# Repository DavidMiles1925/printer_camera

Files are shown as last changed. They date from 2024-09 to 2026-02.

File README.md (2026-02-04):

# Printer Camera

## Project Description

This project was conceived because I have a resin 3D printer that I want to run outside. Because the printer is outside, I need to leave it blocked from sunlight. Therefore, I cannot check on the print by lifting the lid (at least not during the daytime).

The project has now been through 2 interations; once with my Creality LD-002H and again with my Elegoo Mars 5 Ultra.

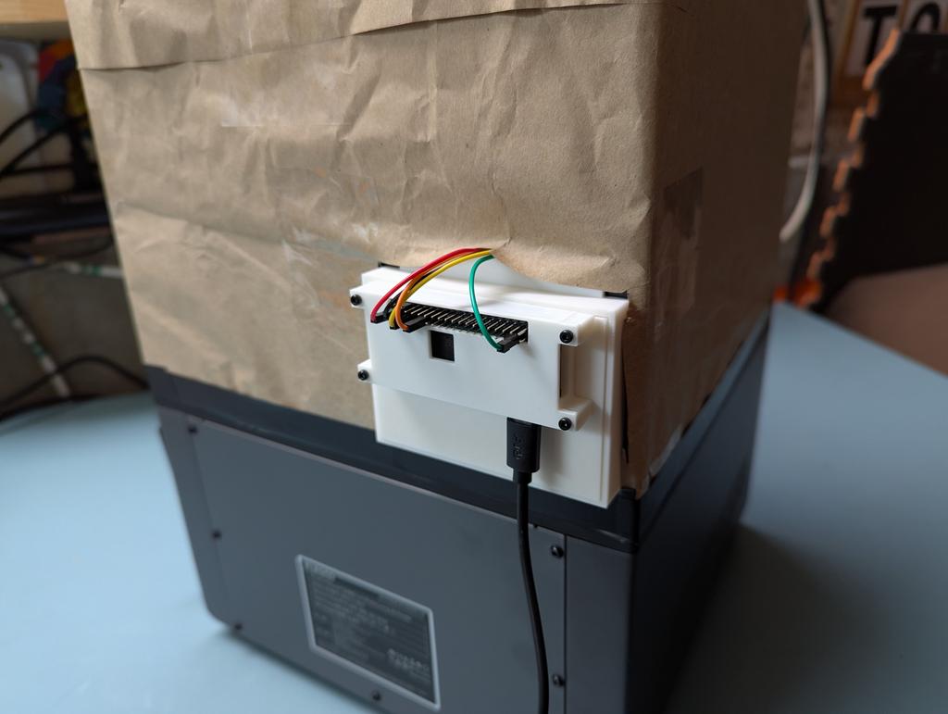
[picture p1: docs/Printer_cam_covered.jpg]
Version 2


### Features

    ✅ Turns on a camera on a set interval
    ✅ Turns on a camera with ad hoc command and/or separate program
    ✅ Turn on light(s) before recording with the camera (and off after recording)
    ✅ Turns on light with ad hoc command and/or separate program
    ✅ Store videos on SSD to be accessed via SSH
    ✅ Record temperature in a log to be accessed via SSH
    ✅ Fully 3D printed shell
    ✅ A script to run on Windows machine for downloading files from the RPi

## Using the Software

### Clone Repo:

```bash
git clone https://github.com/DavidMiles1925/printer_camera.git
```

### Dependencies:

**Note: These _MUST_ be installed prior to using this software.**

#### picamera2

> This is the library used to interact with the RPi Camera Module
>
> ```bash
> sudo apt install -y python3-picamera2
> ```

#### ffmpeg

> This library gets used to convert .h264 files to .mp4.
>
> ```bash
> sudo apt install -y ffmpeg
> ```

#### paramiko scp

> This will be installed on your **_WINDOWS MACHINE_** to bring files over from the pi.
>
> Ensure that you have set up an SSH Key. [**Documentation for SSH Key Setup Here**](https://github.com/DavidMiles1925/pi_zero_setup#set-up-ssh-key-to-eliminate-need-for-password)
>
> ```bash
> pip install paramiko scp
> ```

### Programs

All programs should be run from the command line.

Options can be configured in `config.py`.

#### `main.py`

> This runs the main app which takes a video every `{CAMERA_RECORDING_TIME}` seconds.
>
> **Before running make sure these options are configured!**
>
> `SAVE_DIRECTORY_PATH` and `LOG_DIRECTORY_PATH` have the correct Pi Name in their directory path.
>
> `FILENAME_PREFIX` has a descriptor that acurately describes the material being recorded.
>
> | Option                         | Possible Values                                 | Purpose                                                                                              |
> | :----------------------------- | :---------------------------------------------- | :--------------------------------------------------------------------------------------------------- |
> | `VIDEO_RECORDING_ON`           | True/False                                      | Turn video recording feature on or off                                                               |
> | `CAMERA_RECORDING_TIME`        | Any Number                                      | Seconds that the camera will record if activated                                                     |
> | `TIME_BETWEEN_LOOP_ITERATIONS` | Any Number                                      | Seconds between checks for feature activation (not including the length of the video recording)      |
> | `FILENAME_PREFIX`              | Any String - Do NOT include spaces in the name. | This is will be filename, followed by a number                                                       |
> | `DIRECTORY_NAME_PREFIX`        | Any String                                      | This is the directory name prefix where videos will be stored                                        |
> | `SAVE_DIRECTORY_PATH`          | "/home/[PI NAME]/printer_camera/recordings/"    | The directory where recordings will be stored                                                        |
> | `LIGHTING_ON`                  | True/False                                      | This determines whether the light will turn on WHILE THE CAMERA IS RUNNING                           |
> | `LIGHT_ALWAYS_ON`              | True/ False                                     | This will determine if the light is ALWAYS ON while the program is running EVEN IF THE CAMERA IS NOT |
> | `LOG_DIRECTORY_PATH`           | "/home/[PI NAME]/printer_camera/logs"           | This is the directory name prefix where logs will be stored                                          |

#### `temp.py`

> This program, when run by iteself, will log the current temperature and print it to the console intermitently.
>
> This module is used in main.py to log the temperature each time the camera records a video.
>
> | Option                   | Possible Values | Purpose                                                                       |
> | :----------------------- | :-------------- | :---------------------------------------------------------------------------- |
> | `TEMPERATURE_LOGGING_ON` | True/False      | This determines whether the temperature will be logged when `main.py` is run. |
> | `TEMP_LOG_TIME_`         | Any Number      | The amount of time in seconds between logging when **`temp.py`** is run       |

#### `camera_and_light.py`

> This program is a stand-alone app used for testing the camera or grabbing an ad hoc picture/video.
>
> It can also be used to toggle lights in the chamber on and off.
>
> Photos are saved in .jpg format.
>
> Videos are stored in .mp4 format (after being converted from .h264)
>
> | Option                  | Possible Values      | Purpose                                                                  |
> | :---------------------- | :------------------- | :----------------------------------------------------------------------- |
> | `SINGLE_RECORDING_TIME` | Any Number           | The length of the video to be recorded in seconds                        |
> | `LIGHT_PIN_1`           | BCM number from GPIO | This pin will be used for an LED to light the chamber                    |
> | `LIGHT_PIN_2`           | BCM number from GPIO | This pin will be used for an LED to light the chamber                    |
> | `DISABLE_CAMERA`        | True/False           | Turn to `True` to be able to disconnect RPi Camera Module without errors |

#### pull_files.py

> This program is only to be run on a windows machine.
>
> You **_MUST_** have set up an SSK Key. [**Documentation for SSH Key Setup Here**](https://github.com/DavidMiles1925/pi_zero_setup#set-up-ssh-key-to-eliminate-need-for-password)
>
> | Option              | Possible Values  | Purpose                                           |
> | :------------------ | :--------------- | :------------------------------------------------ |
> | `REMOTE_HOST`       | RPi IP Address   | The IP address of the RPi for ssh connection      |
> | `PI_USERNAME`       | RPi Username     | The username of the RPi                           |
> | `WIN_USERNAME`      | Windows Username | The username of the Windows account pulling files |
> | `REMOTE_PATH_PHOTO` | File Path        | Path to grab photo files from                     |
> | `REMOTE_PATH_VIDEO` | File Path        | Path to grab video files from                     |
> | `LOCAL_PATH`        | File path        | Path where files will be downloaded               |
>
> **Manual Copy/Paste commands to pull videos.**
>
> ```bash
> scp -r PI_NAME@192.168.1.000:/home/PI_NAME/printer_camera/recordings/ /c/users/USER_NAME/downloads
> scp -r PI_NAME@192.168.1.000:/home/PI_NAME/printer_camera/logs/ /c/users/USER_NAME/downloads
> ```

---

## Developer Notes

The majority of the original code as repurposed from the [**motion_camera**](https://github.com/DavidMiles1925/motion_camera) repo. Look there for more detailed documetnation.

### Materials

| Material | Quantity | Link |
| :--- | :---: | :--- |
| Raspberri Pi Zero 2 W (with header pins) | 1 | |
| SD Card Formatted with Raspberry Pi OS | 1 | |
| Raspberri Pi Camera Module | 1 | |
| Breadboard | 1 | |
| 3D Printed Shell | 2 | [Printed Shell](./print_files/) |
| 100Ω Resistor (for lights) | 2 | |
| 4.7KΩ Resistor (for temperature sensor)  | 1 | |
| DuPont Cables M-F (short) | 5 | |

### Wiring

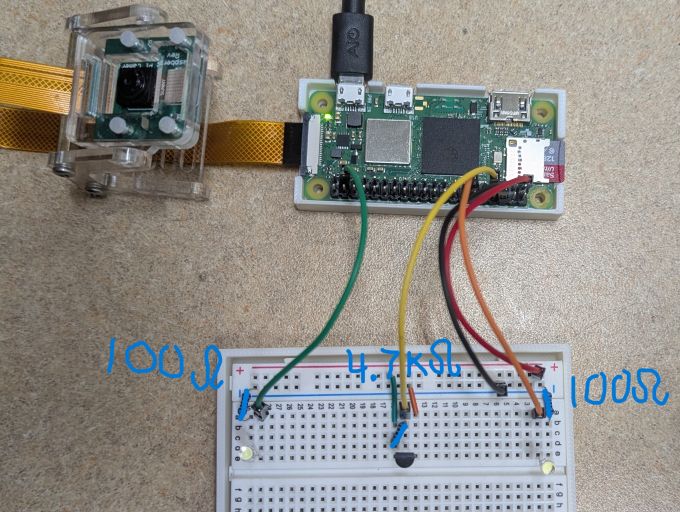
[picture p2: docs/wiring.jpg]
Wiring


### Pin assignments:

| Pin Name | Pin Number (BCM) | Purpose |
| :--- | :--- | :--- |
| LIGHT_1_PIN | 17 | Lighting: Brightening the printing chamber |
| LIGHT_2_PIN | 26 | Lighting: Brightening the printing chamber |
| N/A | GND (any) | Lighting: Ground |
| 1-Wire Connection | 4 | Temperature Sensor: THIS WILL REQUIRE ADDITIONAL STEPS |
| N/A | GND (any) | Temperature Sensor: Ground |
| N/A | 5V | Temperature Sensor: Power |

**PiCamera must be properly connected or program will not run.**

### Camera

#### Camera Installation

> You will need to ensure picamera2 is installed on your machine. (see Dependencies above)
>
> I have documented the setup of the camera extensively in the [**Motion Camera Repo**](https://github.com/DavidMiles1925/motion_camera). Refer to this documentation for more information.
>
> Ensure the camera is installed (in the RPI Zero 2 W) with the gold traces facing the board ("face-down").
>
> The side of the camera with the cable running in is the bottom of the camera.
>
> The RPi must be booted with the camera attached. If it is attached afterwards, the program will throw an error.

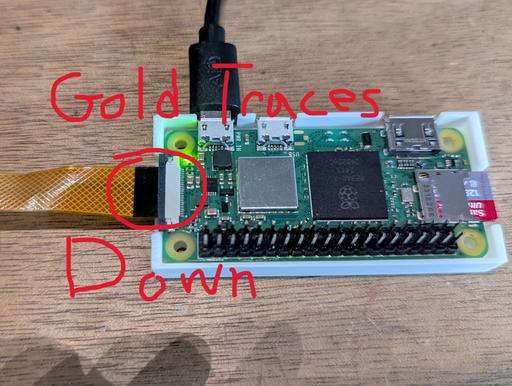
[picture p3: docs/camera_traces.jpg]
Camera Traces


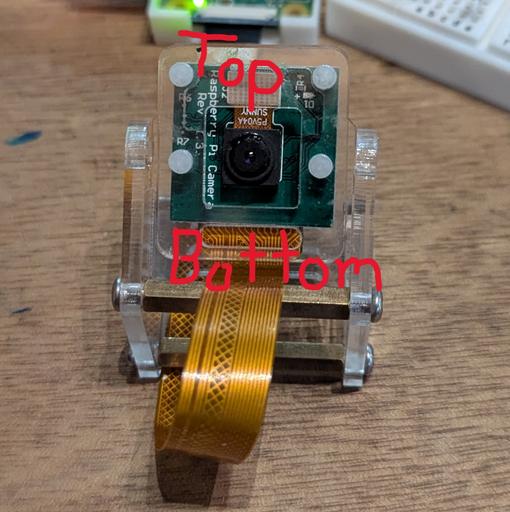
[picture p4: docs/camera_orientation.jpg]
Camera Orientation


### Temperature Sensor: DS18B20

#### One-Wire Interface

One-Wire Interface needs to be enabled to read the data pin. Do this in the RPi config.

**[Documentation](https://pinout.xyz/pinout/1_wire)** can be found here.

**[Tutorial](https://www.circuitbasics.com/raspberry-pi-ds18b20-temperature-sensor-tutorial/)** can be found here.

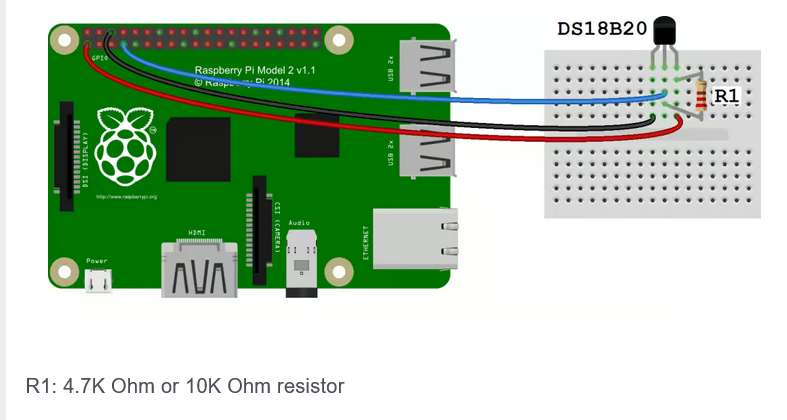
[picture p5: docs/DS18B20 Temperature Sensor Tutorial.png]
Temp Sensor


1. Add to /boot/config.txt

Run the raspberry pi config tool

```bash
sudo raspi-config
```

Select `Interface Options`

Select `1-Wire` and Select "Yes"

2. Reboot

```bash
sudo reboot
```

3. We need to add a bootable kernal to Linux:

```bash
sudo modprobe w1-gpio
sudo modprobe w1-therm
```

4. Change directories and check for attached device:

```bash
cd /sys/bus/w1/devices
ls
```

5. Enter device directory:

```bash
cd 28-XXXXXXXXXXXX
```

6. Check raw temperature readout:

```bash
cat w1_slave
```

#### Code for Temp Sensor

**About**

The library `temp.py` was created using code from the tutorial referenced above.

It was adjusted so that it can be used as a library as well as run as a main function.

The above steps will need to be completed before the code can be run.

**Integration**

I set up the log function to take `prefix=` argument in order to accomodate the temp log.

## 3D Prints

The Version 1 files have been moved to the `/Depricated` folder and will not be used anymore.

Files are located in the `print_files` folder above. The Pi piece and the breadboard piece were glued back-to-back and installed in the fan port on the cover for the Mars 5 Ultra.

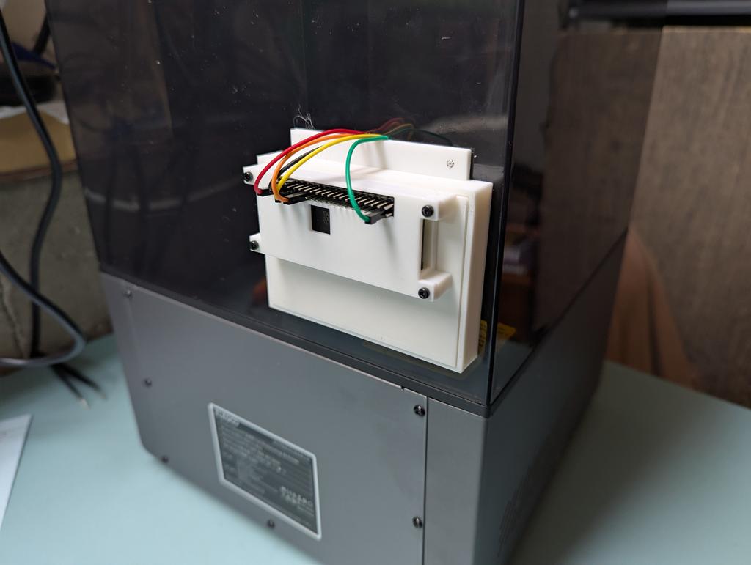
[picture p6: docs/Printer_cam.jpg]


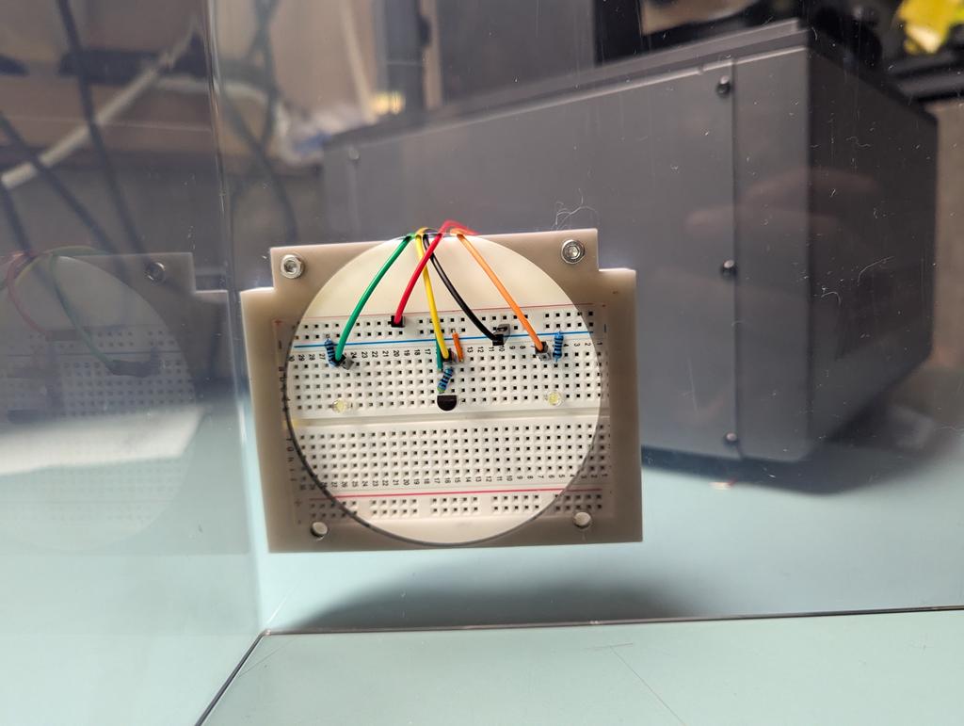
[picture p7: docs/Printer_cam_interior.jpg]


## Gallery

Version 1

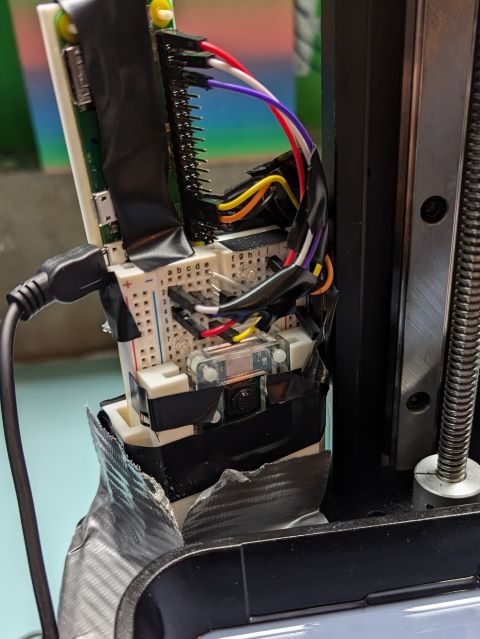
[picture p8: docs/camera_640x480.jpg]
Version 1


Version 2

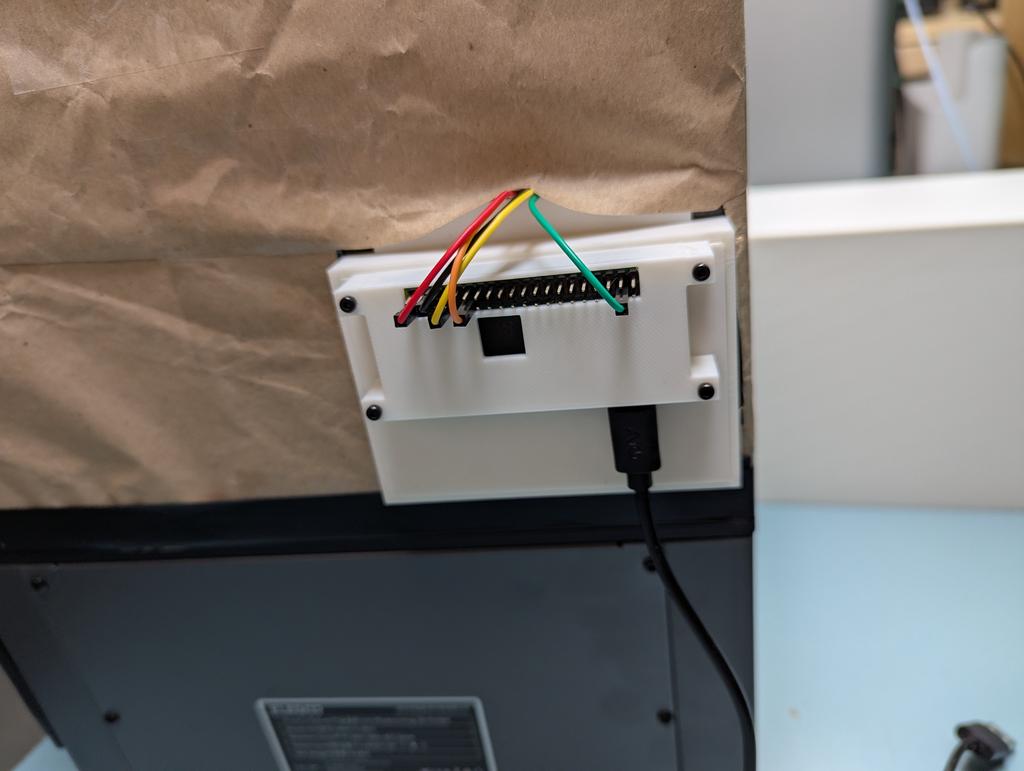
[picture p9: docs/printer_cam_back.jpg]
Version 2 Back


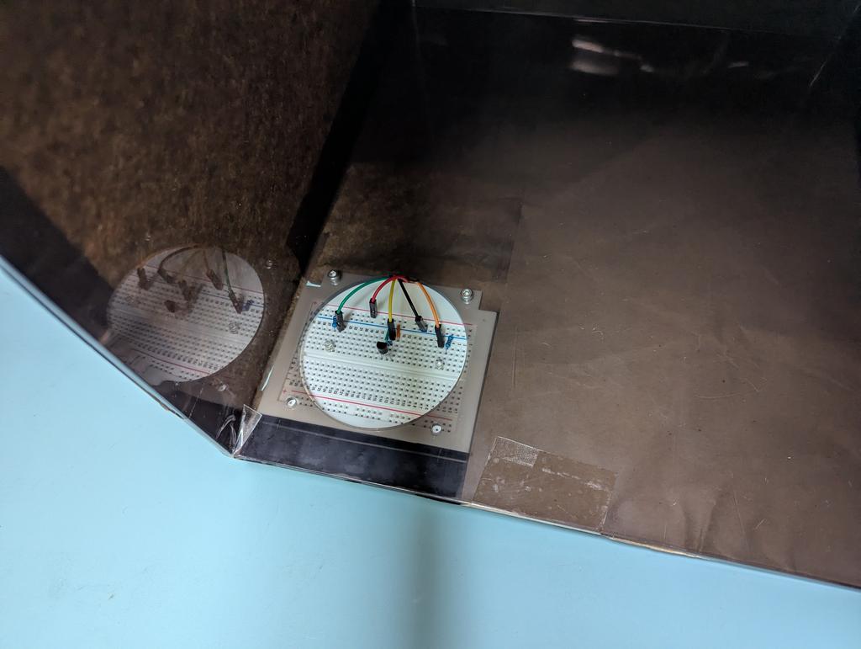
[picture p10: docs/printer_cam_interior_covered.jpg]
Version 2 Interior


#### Other Documentaion Links

**My article on printing outdoors**  
[Article - Outdoor Resin Printinig](https://www.crealitycloud.com/post-detail/66e5a9818b2f34a688458715)

**My YouTube video showing outdoor printing**  
[Video - Outdoor Resin Printing](https://youtu.be/wVPIBC5VqVw)

**Resin Settings from Maker Trainer (for LD-002H)**  
[LD-002H Resin Settings Spreadsheet](https://makertrainer.com/wiki/Creality_LD-002H_resin_settings)

**Resin Settings from Elegoo (for Mars 5 Ultra)**  
Elegoo Resin Settings

**Calibration Model and Tutorial from Ameralabs**  
[Calibration Tutorial](https://ameralabs.com/blog/town-calibration-part/)

## Troubleshooting

### Camera

#### IndexError: list index out of range

means that picamera2 checked for attached cameras but found an empty list.

1. Check physical connection

- Is the camera ribbon cable firmly seated in the CSI port?

- Make sure it's facing the correct direction (metal pins face the camera connector contacts).

- Try reseating the cable on both ends (Pi and camera).

2. Make sure the camera is enabled

Even if you already ran this, double-check:

```bash
sudo raspi-config
```

- Go to: Interface Options → Camera → Enable

#### TypeError: Picamera2.start_recording() missing 1 required positional argument: 'output'

The start_recording() method in picamera2 requires two arguments:

`picam2.start_recording(output, encoder)`

You're currently just passing the filename (filename), but it's expecting a file encoder and a file-like output.

#### 🧪 Test It

After reboot:

libcamera-hello

If it still fails:

    Double-check that your cable is for the Pi Zero (not the wide one for full-size Pis).

    Make sure the camera module itself is firmly connected and supported by the OS.

    Run:

libcamera-still --list-cameras

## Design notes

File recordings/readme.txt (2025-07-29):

This file needs to be here so that this directory is here when the repo is cloned.
Yay stupid solutions!

Update: See camera.py for how to update so I don't need this file!

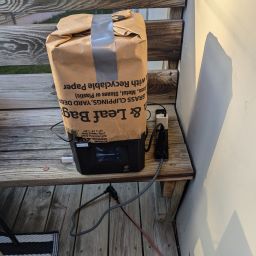
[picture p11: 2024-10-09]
docs/outside.jpg

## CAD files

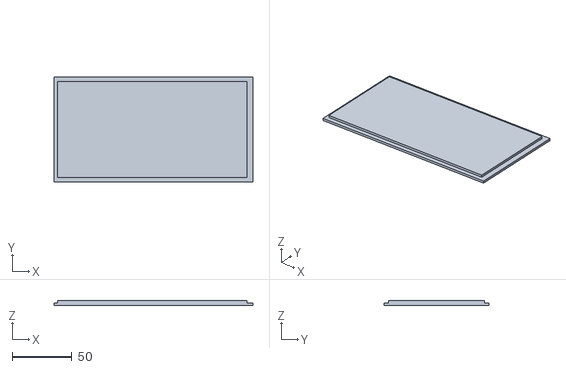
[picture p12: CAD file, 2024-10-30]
print_files/Depricated/Wash_Bin_LD-002H_Build_Volume_Lid.stl
166.0 x 88.0 x 4.00

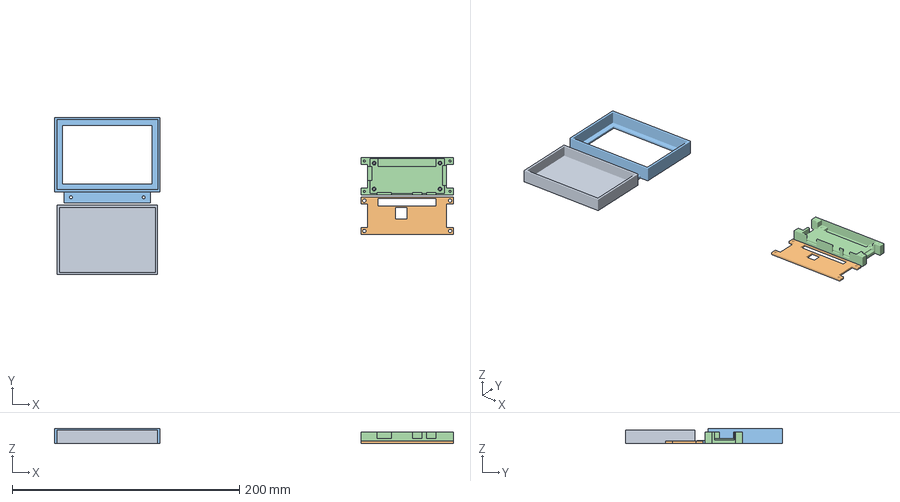
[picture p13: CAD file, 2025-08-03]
print_files/Printer Camera 3D Printed Shell.3mf
351.3 x 138.2 x 13.2 mm
Breadboard Base.stl
Pi Cover.stl
Breadboard Cover.stl
Pi Base.stl

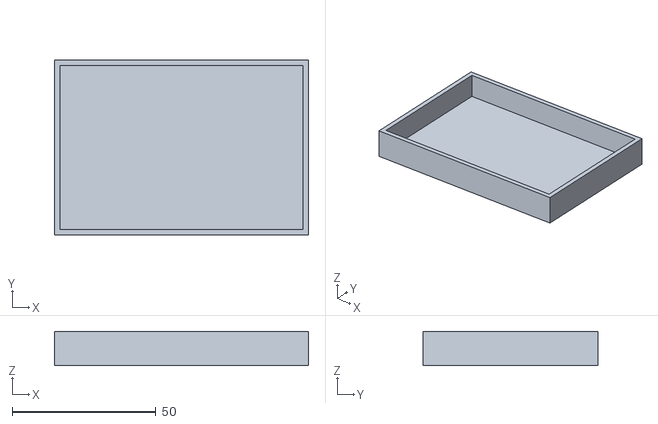
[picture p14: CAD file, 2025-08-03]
print_files/Breadboard Base.stl
88.5 x 61.0 x 12.0

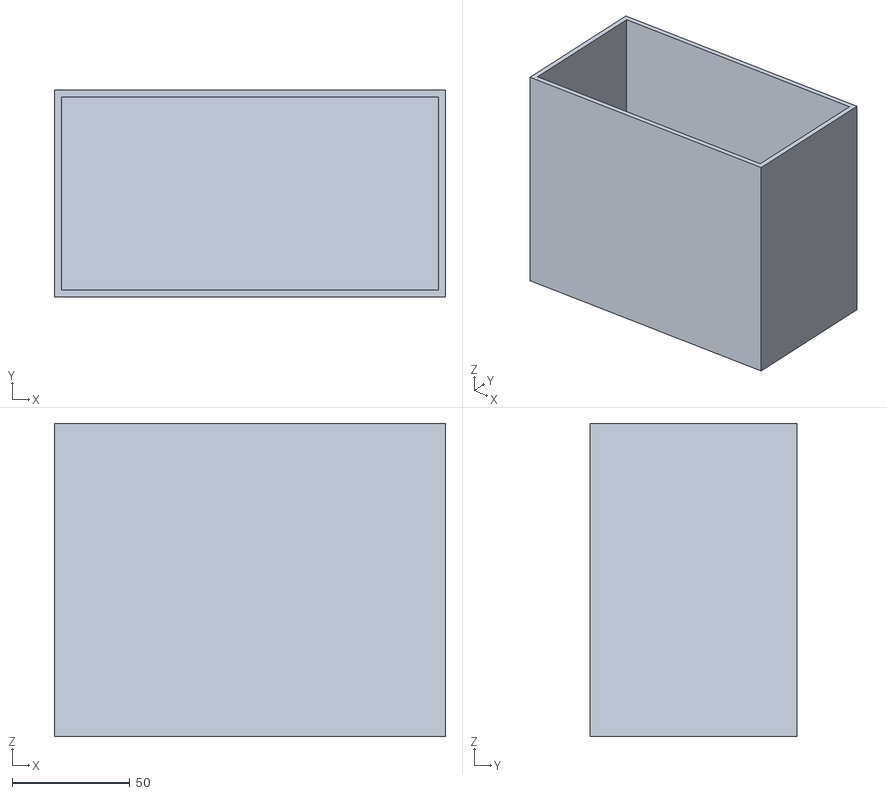
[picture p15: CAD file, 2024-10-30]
print_files/Depricated/Wash_Bin_LD-002H_Build_Volume.stl
166.0 x 88.0 x 133.0

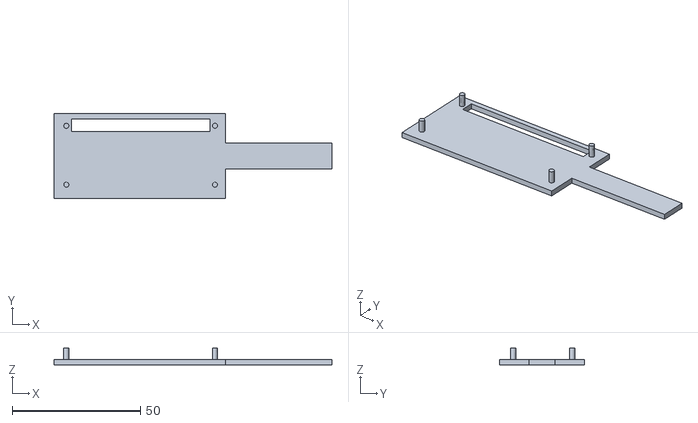
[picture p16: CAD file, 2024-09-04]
print_files/Depricated/Printer_Camera_Holder_Pi_Extension.stl
108.5 x 33.0 x 6.50

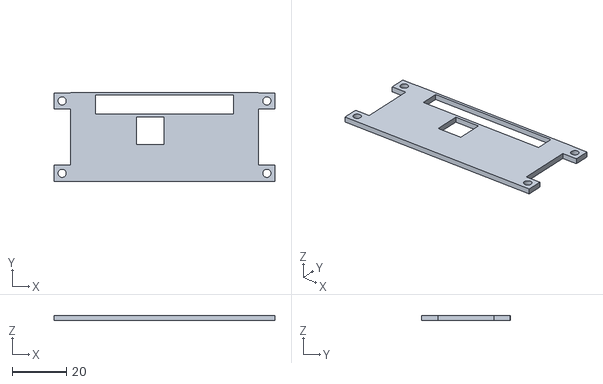
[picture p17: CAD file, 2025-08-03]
print_files/Pi Cover.stl
81.5 x 32.8 x 2.00

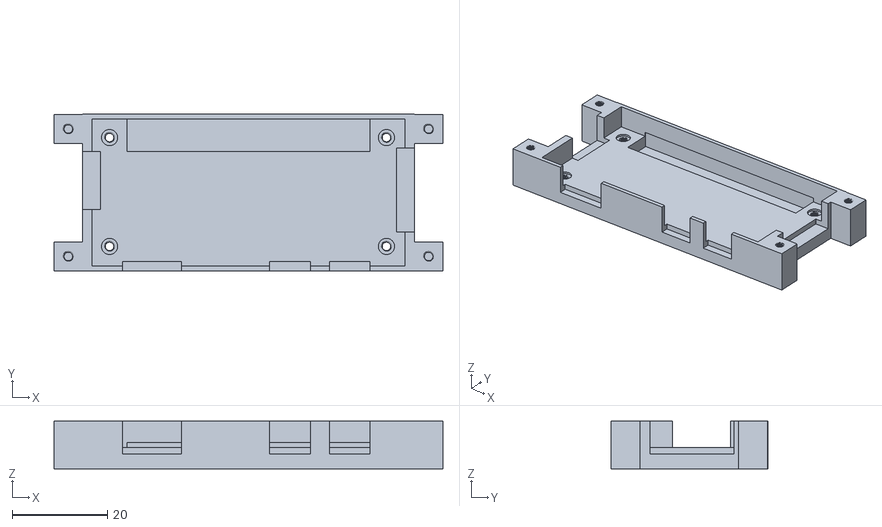
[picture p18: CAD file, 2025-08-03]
print_files/Pi Base.stl
81.5 x 32.8 x 10.0

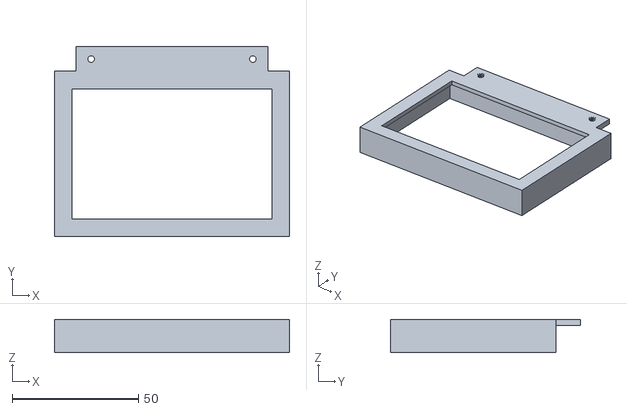
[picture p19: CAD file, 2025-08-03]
print_files/Breadboard Cover.stl
93.0 x 75.2 x 13.2

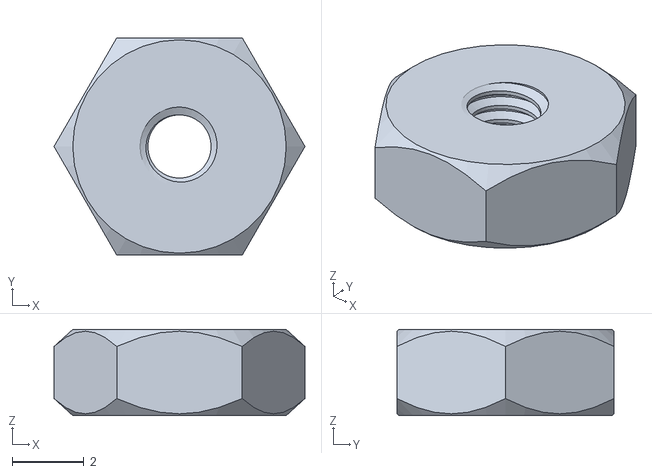
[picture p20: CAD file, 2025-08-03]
print_files/NUT_TEST.stl
6.99 x 6.05 x 2.40

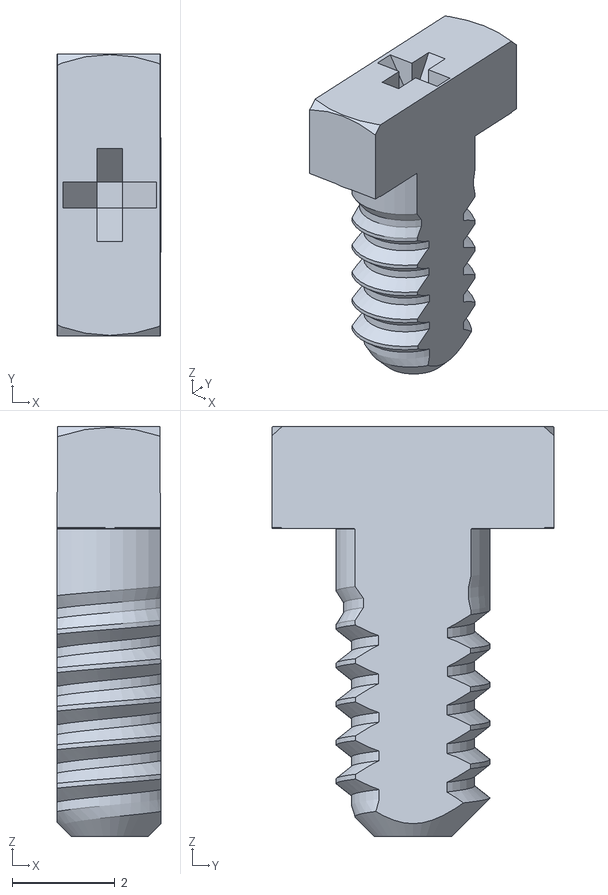
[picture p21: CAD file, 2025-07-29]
print_files/Pi Bolt.stl
2.03 x 5.50 x 7.98

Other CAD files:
print_files/Printer Camera Models.blend

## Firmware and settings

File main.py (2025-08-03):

from datetime import datetime
import RPi.GPIO as GPIO
import os
from picamera2.encoders import H264Encoder
from picamera2 import Picamera2
from time import sleep
from logger import write_to_log

from config import TIME_BETWEEN_LOOP_ITERATIONS, FILENAME_PREFIX, DIRECTORY_NAME_PREFIX, SAVE_DIRECTORY_PATH, CAMERA_RECORDING_TIME, LIGHTING_ON, VIDEO_RECORDING_ON, TEMPERATURE_LOGGING_ON, LIGHT_ALWAYS_ON
from temp import read_temp, construct_temp_string

LIGHT_1_PIN = 17
LIGHT_2_PIN = 26

video_counter = 0
recordings_path_str = "none"

picam2 = Picamera2()
video_config = picam2.create_video_configuration()
picam2.configure(video_config)
encoder = H264Encoder(bitrate=1000000)

# Adds zeros to the video number in the filename.
#   - This was done to ensure videos stayed in chronological
#     order, even when displayed alphabetically.
def add_zeros_to_number(num, amt):
    num_str = str(num)

    num_zeros = amt - len(num_str)

    if num_zeros > 0:
        return '0' * num_zeros + num_str
    else:
        return num_str
    
def setup_pins():
    GPIO.setmode(GPIO.BCM)

    GPIO.setwarnings(False)

    GPIO.setup(LIGHT_1_PIN, GPIO.OUT)
    GPIO.output(LIGHT_1_PIN, GPIO.LOW)

    GPIO.setup(LIGHT_2_PIN, GPIO.OUT)
    GPIO.output(LIGHT_2_PIN, GPIO.LOW)

def set_up_folder():
    global recordings_path_str
    folder_time = datetime.now().strftime("%m.%d.%Y")

    recordings_path_str = f"{SAVE_DIRECTORY_PATH}{DIRECTORY_NAME_PREFIX}{folder_time}"
    
    if os.path.isdir(recordings_path_str) ==  False:
        os.mkdir(recordings_path_str)

    os.chdir(recordings_path_str)

def run_camera():
    global video_counter

    if LIGHT_ALWAYS_ON == False:
        switch_lights(True)

    timestamp = datetime.now().strftime("%H.%M.%S")

    video_counter_str = add_zeros_to_number(video_counter, 3)

    output = FILENAME_PREFIX + "_" + timestamp + ".h264"
    mp4_output = f"{video_counter_str}-{FILENAME_PREFIX}-[{timestamp}].mp4"

    print("Camera Running")

    picam2.start_recording(encoder, output)

    sleep(CAMERA_RECORDING_TIME)
    
    picam2.stop_recording()

    if LIGHT_ALWAYS_ON == False:
        switch_lights(False)

    print(f"Recorded {output}\nConverting to MP4...")

    # Convert H264 to MP4
    conversion_command = f"ffmpeg -i {output} -c copy {mp4_output}"
    os.system(conversion_command)

    # Delete the original H264 file after conversion
    os.remove(output)

    video_counter = video_counter + 1

    print(f"Recorded {mp4_output}")
    write_to_log(f"Camera Off: Recorded {mp4_output}")

    

def switch_lights(light):
    if LIGHTING_ON == True:
        if light == True:
            GPIO.output(LIGHT_1_PIN, GPIO.HIGH)
            GPIO.output(LIGHT_2_PIN, GPIO.HIGH)

        if light == False:
            GPIO.output(LIGHT_1_PIN, GPIO.LOW)
            GPIO.output(LIGHT_2_PIN, GPIO.LOW)

if __name__ == "__main__":
    try:
        print("Program Started")
        write_to_log("Program Started")
        setup_pins()

        if LIGHT_ALWAYS_ON == True:
            switch_lights(True)
        
        while True:
            if VIDEO_RECORDING_ON == True:
                write_to_log("Running Camera")
                set_up_folder()
                run_camera()
            if TEMPERATURE_LOGGING_ON == True:
                write_to_log(construct_temp_string(), "temp_")
            sleep(TIME_BETWEEN_LOOP_ITERATIONS)

    except KeyboardInterrupt:
        print("Program terminated with ctrl+c")
        write_to_log("Program terminated with ctrl+c")
        GPIO.cleanup()

    except Exception as e:
        write_to_log(f"Error: {e}")
        print(f"Error: {e}")

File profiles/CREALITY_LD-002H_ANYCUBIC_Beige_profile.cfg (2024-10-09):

__resin:AnyCubic Beige
actualPrintingTimeHour:
actualPrintingTimeMinute:
actualPrintingTimeSecond:
antiAliasLevel:8
bAntiAliasLevelEditable:0
bAntiAliasing:1
bBottomInnerOutterCircleOffsetEnable:0
bBuildAreaOffsetEnable:0
bDisplayCorrectEnable:0
bImageBlur:0
bImageBlurPixelEditable:1
bImageMask:0
bInnerOutterCircleOffsetEnable:0
bLockXYSizeRatio:1
bPrintTimeCompensationEnable:
bShrinkageXYRatio:0
bSurfaceRoughEditable:0
bVisibleShrinkageXYRatio:1
bottomEdgeExposureMM:0
bottomEdgeExposureTimeS:4
bottomExposureTimeStrategy:0
bottomInnerCircleOffset:0
bottomLayerCount:8
bottomLayerDropHeight2:
bottomLayerDropSpeed:150
bottomLayerDropSpeed2:
bottomLayerExposureTime:12
bottomLayerLiftHeight:5
bottomLayerLiftHeight2:0
bottomLayerLiftSpeed:50
bottomLayerLiftSpeed2:0
bottomLightIntensityPWM:255
bottomLightOffTime:0
bottomLightOffTimeVisible:1
bottomOutterCircleOffset:0
bottomRestTimeAfterLift:0
bottomRestTimeAfterRetract:0
bottomRestTimeBeforeLift:0
buildAreaOffsetBottom:0
buildAreaOffsetLeft:0
buildAreaOffsetRight:0
buildAreaOffsetTop:0
circleParityDifference:0
currProfile:ANYCUBIC Beige
displayCorrectLeftBottomX:0
displayCorrectLeftBottomY:0
displayCorrectLeftTopX:0
displayCorrectLeftTopY:0
displayCorrectRightBottomX:0
displayCorrectRightBottomY:0
displayCorrectRightTopX:0
displayCorrectRightTopY:0
edgeExposureMM:0
edgeExposureTimeS:4
endGcode:"M106 S0;\nG1 Z{machine_height} F25;\nM18;\n"
fillDensity:10
fillPattern:None
imageBlurPixel:2
imageMaskFile:
innerCircleOffset:0
isHALOT:0
isSupportTSMC:0
layerGcode:"M6054 {image};show Image\nG0 Z{rise_pos} F{rise_speed};\nG0 Z{fall_pos} F{fall_speed};\nG4 P{light_delay};\nM106 S{light_pwm};light on\nG4 P{exposure_time};\nM106 S0; light off\n"
layerHeight:0.05
layerPrintTime:
lightOffTime:2
machineDepth:130.56
machineHeight:160
machineType:CREALITY LD-002H
machineWidth:82.62
maskGrayScaleUnit:4
maxGreyLevel:255
minGreyLevel:0
normalExposureTime:1.7
normalLayerDropHeight2:0
normalLayerDropSpeed:150
normalLayerDropSpeed2:0
normalLayerLiftHeight:5
normalLayerLiftHeight2:0
normalLayerLiftSpeed:50
normalLayerLiftSpeed2:0
normalLightIntensityPWM:255
normalRestTimeAfterLift:0
normalRestTimeAfterRetract:0
normalRestTimeBeforeLift:0
outterCircleOffset:0
printWaitMode:0
printingLayer:1
projectType:LCD_mirror
resinDensity:1.1399
resinPrice:25.29
resinUnit:$/L
resolutionX:1620
resolutionY:2560
shellThickness:1.2
sliceExportPart:0
softwareForecastTimeHour:
softwareForecastTimeMinute:
softwareForecastTimeSecond:
startGcode:"G21;\nG90;\nM106 S0;\nG28 Z0;\n"
surfaceRoughLevel:1
transitionLayerCount:0
transitionLayerType:0
waitModeChangedVisible:1
xShrinkageCompensation:100
yShrinkageCompensation:100
zShrinkageCompensation:100
zSlowUpDistance:0
@@ANYCUBIC Beige@@__resin:AnyCubic Beige
@@ANYCUBIC Beige@@actualPrintingTimeHour:
@@ANYCUBIC Beige@@actualPrintingTimeMinute:
@@ANYCUBIC Beige@@actualPrintingTimeSecond:
@@ANYCUBIC Beige@@antiAliasLevel:8
@@ANYCUBIC Beige@@bAntiAliasLevelEditable:0
@@ANYCUBIC Beige@@bAntiAliasing:1
@@ANYCUBIC Beige@@bBottomInnerOutterCircleOffsetEnable:0
@@ANYCUBIC Beige@@bBuildAreaOffsetEnable:0
@@ANYCUBIC Beige@@bDisplayCorrectEnable:0
@@ANYCUBIC Beige@@bImageBlur:0
@@ANYCUBIC Beige@@bImageBlurPixelEditable:1
@@ANYCUBIC Beige@@bImageMask:0
@@ANYCUBIC Beige@@bInnerOutterCircleOffsetEnable:0
@@ANYCUBIC Beige@@bLockXYSizeRatio:1
@@ANYCUBIC Beige@@bPrintTimeCompensationEnable:
@@ANYCUBIC Beige@@bShrinkageXYRatio:0
@@ANYCUBIC Beige@@bSurfaceRoughEditable:0
@@ANYCUBIC Beige@@bVisibleShrinkageXYRatio:1
@@ANYCUBIC Beige@@bottomEdgeExposureMM:0
@@ANYCUBIC Beige@@bottomEdgeExposureTimeS:4
@@ANYCUBIC Beige@@bottomExposureTimeStrategy:0
@@ANYCUBIC Beige@@bottomInnerCircleOffset:0
@@ANYCUBIC Beige@@bottomLayerCount:8
@@ANYCUBIC Beige@@bottomLayerDropHeight2:
@@ANYCUBIC Beige@@bottomLayerDropSpeed:150
@@ANYCUBIC Beige@@bottomLayerDropSpeed2:
@@ANYCUBIC Beige@@bottomLayerExposureTime:12
@@ANYCUBIC Beige@@bottomLayerLiftHeight:5
@@ANYCUBIC Beige@@bottomLayerLiftHeight2:0
@@ANYCUBIC Beige@@bottomLayerLiftSpeed:50
@@ANYCUBIC Beige@@bottomLayerLiftSpeed2:0
@@ANYCUBIC Beige@@bottomLightIntensityPWM:255
@@ANYCUBIC Beige@@bottomLightOffTime:0
@@ANYCUBIC Beige@@bottomLightOffTimeVisible:1
@@ANYCUBIC Beige@@bottomOutterCircleOffset:0
@@ANYCUBIC Beige@@bottomRestTimeAfterLift:0
@@ANYCUBIC Beige@@bottomRestTimeAfterRetract:0
@@ANYCUBIC Beige@@bottomRestTimeBeforeLift:0
@@ANYCUBIC Beige@@buildAreaOffsetBottom:0
@@ANYCUBIC Beige@@buildAreaOffsetLeft:0
@@ANYCUBIC Beige@@buildAreaOffsetRight:0
@@ANYCUBIC Beige@@buildAreaOffsetTop:0
@@ANYCUBIC Beige@@circleParityDifference:0
@@ANYCUBIC Beige@@currProfile:ANYCUBIC Gray
@@ANYCUBIC Beige@@currProfileName:ANYCUBIC Beige
@@ANYCUBIC Beige@@displayCorrectLeftBottomX:0
@@ANYCUBIC Beige@@displayCorrectLeftBottomY:0
@@ANYCUBIC Beige@@displayCorrectLeftTopX:0
@@ANYCUBIC Beige@@displayCorrectLeftTopY:0
@@ANYCUBIC Beige@@displayCorrectRightBottomX:0
@@ANYCUBIC Beige@@displayCorrectRightBottomY:0
@@ANYCUBIC Beige@@displayCorrectRightTopX:0
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

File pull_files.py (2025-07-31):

# This file is only to be used from a windows machine that has been paired with a Pi via SSH Key

from scp import SCPClient
from scp import SCPException
from time import sleep

try:
    from paramiko import SSHClient, AutoAddPolicy
    from paramiko.ssh_exception import AuthenticationException
except:
    print("\nparmiko not installed\n")
    pass

from config import REMOTE_HOST, REMOTE_PATH_PHOTO, REMOTE_PATH_VIDEO, LOCAL_PATH, PI_USERNAME

def progress(filename, size, sent):
    percent = (sent / size) * 100 if size != 0 else 100
    print(f"\rTransferring {filename}: {percent:.1f}% ({sent}/{size} bytes)", end="")

def fetch_files():
    
        print(f"Connecting to {REMOTE_HOST}...")

        ssh = SSHClient()
        ssh.set_missing_host_key_policy(AutoAddPolicy())
        ssh.connect(REMOTE_HOST, username=PI_USERNAME)  # No password needed with SSH key

        with SCPClient(ssh.get_transport(), progress=progress) as scp:
            print(f"Fetching files...")
            if REMOTE_PATH_PHOTO:
                scp.get(REMOTE_PATH_PHOTO, LOCAL_PATH, recursive=True)
            if REMOTE_PATH_VIDEO:
                scp.get(REMOTE_PATH_VIDEO, LOCAL_PATH, recursive=True)

        ssh.close()
        print(f"\n\nDone! Files copied to {LOCAL_PATH}")
        sleep(2)


if __name__ == "__main__":
    print("program started")
    sleep(1)

    try:
        fetch_files()

    except NameError as e:
        print(e.__class__)
        print(e)
        print("\n\n")
        print("HOW TO SOLVE:")
        print("If 'paramiko not installed' is displayed above, run this command:\n")
        print("pip install paramiko\n")
        print("Press any key...")
        input()


    except FileNotFoundError as e:
        print(e.__class__)
        print(e)
        print("\n\n")
        print("HOW TO SOLVE:")
        print("Configure WIN_USERNAME in the config.py file.\n")
        print("Press any key...")
        input()

    except TimeoutError as e:
        print(e.__class__)
        print(e)
        print("\n\n")
        print("HOW TO SOLVE:")
        print("Please check that the device is turned on.")
        print("Check REMOTE_HOST in the config.py file.\n")
        print("Press any key...")
        input()

    except SCPException as e:
        print(e.__class__)
        print(e)
        print("\n\n")
        print("HOW TO SOLVE:")
        print("If 'No such file or directory' is displayed above...")
        print("    Check that the file paths in config.py are correct.")
        print("    Check the file path exists.\n")
        print("Otherwise, retry running program. This error can be caused by a dropped connection.\n")
        print("Press any key...")
        input()

    except AuthenticationException as e:
        print(e.__class__)
        print(e)
        print("\n\n")
        print("HOW TO SOLVE:")
        print("Please configure PI_USERNAME in the config.py file.\n")
        print("Press any key...")
        input()

    except Exception as e:
        print(e.__class__)
        print(e)
        print("\n\n")
        print("Press any key...")
        input()

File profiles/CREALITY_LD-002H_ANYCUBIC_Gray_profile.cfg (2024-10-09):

__resin:AnyCubic Gray
actualPrintingTimeHour:
actualPrintingTimeMinute:
actualPrintingTimeSecond:
antiAliasLevel:8
bAntiAliasLevelEditable:0
bAntiAliasing:1
bBottomInnerOutterCircleOffsetEnable:0
bBuildAreaOffsetEnable:0
bDisplayCorrectEnable:0
bImageBlur:0
bImageBlurPixelEditable:1
bImageMask:0
bInnerOutterCircleOffsetEnable:0
bLockXYSizeRatio:1
bPrintTimeCompensationEnable:
bShrinkageXYRatio:0
bSurfaceRoughEditable:0
bVisibleShrinkageXYRatio:1
bottomEdgeExposureMM:0
bottomEdgeExposureTimeS:4
bottomExposureTimeStrategy:0
bottomInnerCircleOffset:0
bottomLayerCount:8
bottomLayerDropHeight2:
bottomLayerDropSpeed:150
bottomLayerDropSpeed2:
bottomLayerExposureTime:12
bottomLayerLiftHeight:5
bottomLayerLiftHeight2:0
bottomLayerLiftSpeed:50
bottomLayerLiftSpeed2:0
bottomLightIntensityPWM:255
bottomLightOffTime:0
bottomLightOffTimeVisible:1
bottomOutterCircleOffset:0
bottomRestTimeAfterLift:0
bottomRestTimeAfterRetract:0
bottomRestTimeBeforeLift:0
buildAreaOffsetBottom:0
buildAreaOffsetLeft:0
buildAreaOffsetRight:0
buildAreaOffsetTop:0
circleParityDifference:0
currProfile:ANYCUBIC Gray
displayCorrectLeftBottomX:0
displayCorrectLeftBottomY:0
displayCorrectLeftTopX:0
displayCorrectLeftTopY:0
displayCorrectRightBottomX:0
displayCorrectRightBottomY:0
displayCorrectRightTopX:0
displayCorrectRightTopY:0
edgeExposureMM:0
edgeExposureTimeS:4
endGcode:"M106 S0;\nG1 Z{machine_height} F25;\nM18;\n"
fillDensity:10
fillPattern:None
imageBlurPixel:2
imageMaskFile:
innerCircleOffset:0
isHALOT:0
isSupportTSMC:0
layerGcode:"M6054 {image};show Image\nG0 Z{rise_pos} F{rise_speed};\nG0 Z{fall_pos} F{fall_speed};\nG4 P{light_delay};\nM106 S{light_pwm};light on\nG4 P{exposure_time};\nM106 S0; light off\n"
layerHeight:0.05
layerPrintTime:
lightOffTime:2
machineDepth:130.56
machineHeight:160
machineType:CREALITY LD-002H
machineWidth:82.62
maskGrayScaleUnit:4
maxGreyLevel:255
minGreyLevel:0
normalExposureTime:1.9
normalLayerDropHeight2:0
normalLayerDropSpeed:150
normalLayerDropSpeed2:0
normalLayerLiftHeight:5
normalLayerLiftHeight2:0
normalLayerLiftSpeed:50
normalLayerLiftSpeed2:0
normalLightIntensityPWM:255
normalRestTimeAfterLift:0
normalRestTimeAfterRetract:0
normalRestTimeBeforeLift:0
outterCircleOffset:0
printWaitMode:0
printingLayer:1
projectType:LCD_mirror
resinDensity:1.1399
resinPrice:19.84
resinUnit:$/L
resolutionX:1620
resolutionY:2560
shellThickness:1.2
sliceExportPart:0
softwareForecastTimeHour:
softwareForecastTimeMinute:
softwareForecastTimeSecond:
startGcode:"G21;\nG90;\nM106 S0;\nG28 Z0;\n"
surfaceRoughLevel:1
transitionLayerCount:0
transitionLayerType:0
waitModeChangedVisible:1
xShrinkageCompensation:100
yShrinkageCompensation:100
zShrinkageCompensation:100
zSlowUpDistance:0
@@ANYCUBIC Gray@@__resin:AnyCubic Gray
@@ANYCUBIC Gray@@actualPrintingTimeHour:
@@ANYCUBIC Gray@@actualPrintingTimeMinute:
@@ANYCUBIC Gray@@actualPrintingTimeSecond:
@@ANYCUBIC Gray@@antiAliasLevel:8
@@ANYCUBIC Gray@@bAntiAliasLevelEditable:0
@@ANYCUBIC Gray@@bAntiAliasing:1
@@ANYCUBIC Gray@@bBottomInnerOutterCircleOffsetEnable:0
@@ANYCUBIC Gray@@bBuildAreaOffsetEnable:0
@@ANYCUBIC Gray@@bDisplayCorrectEnable:0
@@ANYCUBIC Gray@@bImageBlur:0
@@ANYCUBIC Gray@@bImageBlurPixelEditable:1
@@ANYCUBIC Gray@@bImageMask:0
@@ANYCUBIC Gray@@bInnerOutterCircleOffsetEnable:0
@@ANYCUBIC Gray@@bLockXYSizeRatio:1
@@ANYCUBIC Gray@@bPrintTimeCompensationEnable:
@@ANYCUBIC Gray@@bShrinkageXYRatio:0
@@ANYCUBIC Gray@@bSurfaceRoughEditable:0
@@ANYCUBIC Gray@@bVisibleShrinkageXYRatio:1
@@ANYCUBIC Gray@@bottomEdgeExposureMM:0
@@ANYCUBIC Gray@@bottomEdgeExposureTimeS:4
@@ANYCUBIC Gray@@bottomExposureTimeStrategy:0
@@ANYCUBIC Gray@@bottomInnerCircleOffset:0
@@ANYCUBIC Gray@@bottomLayerCount:8
@@ANYCUBIC Gray@@bottomLayerDropHeight2:
@@ANYCUBIC Gray@@bottomLayerDropSpeed:150
@@ANYCUBIC Gray@@bottomLayerDropSpeed2:
@@ANYCUBIC Gray@@bottomLayerExposureTime:12
@@ANYCUBIC Gray@@bottomLayerLiftHeight:5
@@ANYCUBIC Gray@@bottomLayerLiftHeight2:0
@@ANYCUBIC Gray@@bottomLayerLiftSpeed:50
@@ANYCUBIC Gray@@bottomLayerLiftSpeed2:0
@@ANYCUBIC Gray@@bottomLightIntensityPWM:255
@@ANYCUBIC Gray@@bottomLightOffTime:0
@@ANYCUBIC Gray@@bottomLightOffTimeVisible:1
@@ANYCUBIC Gray@@bottomOutterCircleOffset:0
@@ANYCUBIC Gray@@bottomRestTimeAfterLift:0
@@ANYCUBIC Gray@@bottomRestTimeAfterRetract:0
@@ANYCUBIC Gray@@bottomRestTimeBeforeLift:0
@@ANYCUBIC Gray@@buildAreaOffsetBottom:0
@@ANYCUBIC Gray@@buildAreaOffsetLeft:0
@@ANYCUBIC Gray@@buildAreaOffsetRight:0
@@ANYCUBIC Gray@@buildAreaOffsetTop:0
@@ANYCUBIC Gray@@circleParityDifference:0
@@ANYCUBIC Gray@@currProfile:Transparent Resin
@@ANYCUBIC Gray@@currProfileName:ANYCUBIC Gray
@@ANYCUBIC Gray@@displayCorrectLeftBottomX:0
@@ANYCUBIC Gray@@displayCorrectLeftBottomY:0
@@ANYCUBIC Gray@@displayCorrectLeftTopX:0
@@ANYCUBIC Gray@@displayCorrectLeftTopY:0
@@ANYCUBIC Gray@@displayCorrectRightBottomX:0
@@ANYCUBIC Gray@@displayCorrectRightBottomY:0
@@ANYCUBIC Gray@@displayCorrectRightTopX:0
@@ANYCUBIC Gray@@displayCorrectRightTopY:0
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

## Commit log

2024-09-04 add temp.py, ready for testing
    [Printer_Camera_Holder_Pi_Extension.stl]
2024-09-14 readme update: pins and camera
2024-10-09 readme update: printer notes
    [CREALITY_LD-002H_ANYCUBIC_Beige_profile.cfg, CREALITY_LD-002H_ANYCUBIC_Gray_profile.cfg, CREALITY_LD-002H_SULNU_Clear_Blue_profile.cfg]
2024-10-30 print files: wash bin
    [Wash_Bin_LD-002H_Build_Volume.stl, Wash_Bin_LD-002H_Build_Volume_Lid.stl]
2025-07-29 add stand-alone camera functions
    [Breadboard Base.stl, Pi Base.stl, Pi Bolt.stl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]
2025-07-29 fix TyoeError in recording video
    [camera.py, config.py]
2025-07-29 add recording directory for camera utility
2025-07-29 add conversion to mp4 in camera utility
    [Printer Camera Models.blend]
2025-07-29 fix file extension in mp4 conversion
    [camera_and_lights.py]
2025-07-29 add temperature readout to camera utility
2025-07-29 add CAMERA_DISABLED function
2025-07-31 update pull_files config
    [Printer Camera Models.blend]
2025-07-31 add robust error handling
    [config.py, pull_files.py]
2025-07-31 fix bug where LED turned on at startup
    [camera_and_lights.py, config.py]
2025-08-03 Disable Camera = True
    [Breadboard Cover.stl]
2025-08-03 add some error handling to temp.py
    [temp.py]
2025-08-03 3D shell installed
    [Breadboard Base.stl, NUT_TEST.stl, Pi Base.stl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]
